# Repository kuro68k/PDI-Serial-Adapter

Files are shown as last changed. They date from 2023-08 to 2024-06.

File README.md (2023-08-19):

# PDI Serial Adapter
 Add logic level RS232 to the PDI/UPDI header, with an FTDI breakout

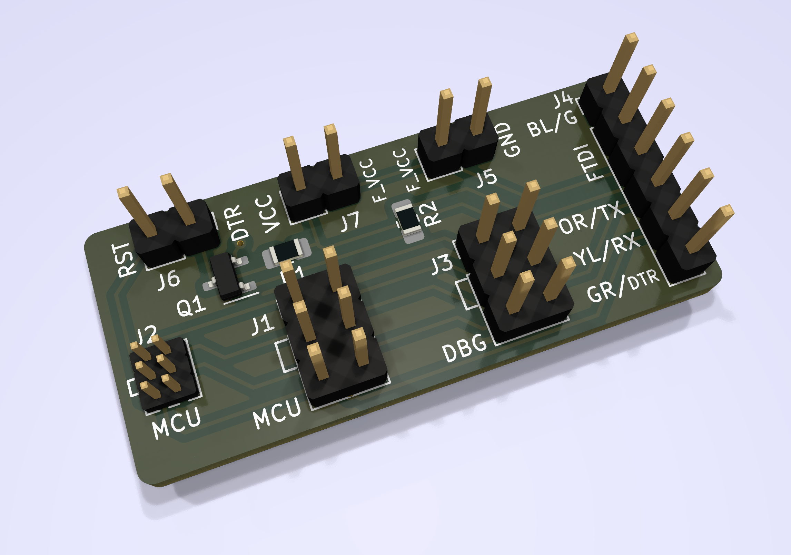
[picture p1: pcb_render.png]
raytraced PCB render


A simple 2 layer board with 3x (U)PDI headers, and an FTDI cable header. A debug serial port is really handy, and STM debuggers have one built in.

J1 (U)PDI cable to target MCU, 2.54mm pitch<br>
J2 (U)PDI cable to target MCU, 1.27mm pitch<br>
J3 (U)PDI header for debugger/programmer
J4 FTDI cable header for TTL level RS232 and USB power
J5 Easy access to FTDI_VCC (5V or 3.3V depending on the cable)
J6 Connects FTDI_DTR to MCU's reset line via open drain

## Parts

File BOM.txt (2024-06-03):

Qty	Ref	Value		Footprint
1	J1	2.54		Connector_PinHeader_2.54mm:PinHeader_2x03_P2.54mm_Vertical
1	J2	1.27		Connector_PinHeader_1.27mm:PinHeader_2x03_P1.27mm_Vertical
1	J3	PROG		Connector_PinHeader_2.54mm:PinHeader_2x03_P2.54mm_Vertical
1	J4	FTDI		Connector_PinHeader_2.54mm:PinHeader_1x06_P2.54mm_Vertical
1	J5	FTDI_VCC	Connector_PinHeader_2.54mm:PinHeader_1x02_P2.54mm_Vertical
1	J6	DTR_RST		Connector_PinHeader_2.54mm:PinHeader_1x02_P2.54mm_Vertical
1	J7	TARGET_PWR	Connector_PinHeader_2.54mm:PinHeader_1x02_P2.54mm_Vertical
1	Q1	BSS138		Package_TO_SOT_SMD:SOT-23
1	R1	100k		Resistor_SMD:R_0805_2012Metric_Pad1.20x1.40mm_HandSolder
1	R2	1k			Resistor_SMD:R_0805_2012Metric_Pad1.20x1.40mm_HandSolder

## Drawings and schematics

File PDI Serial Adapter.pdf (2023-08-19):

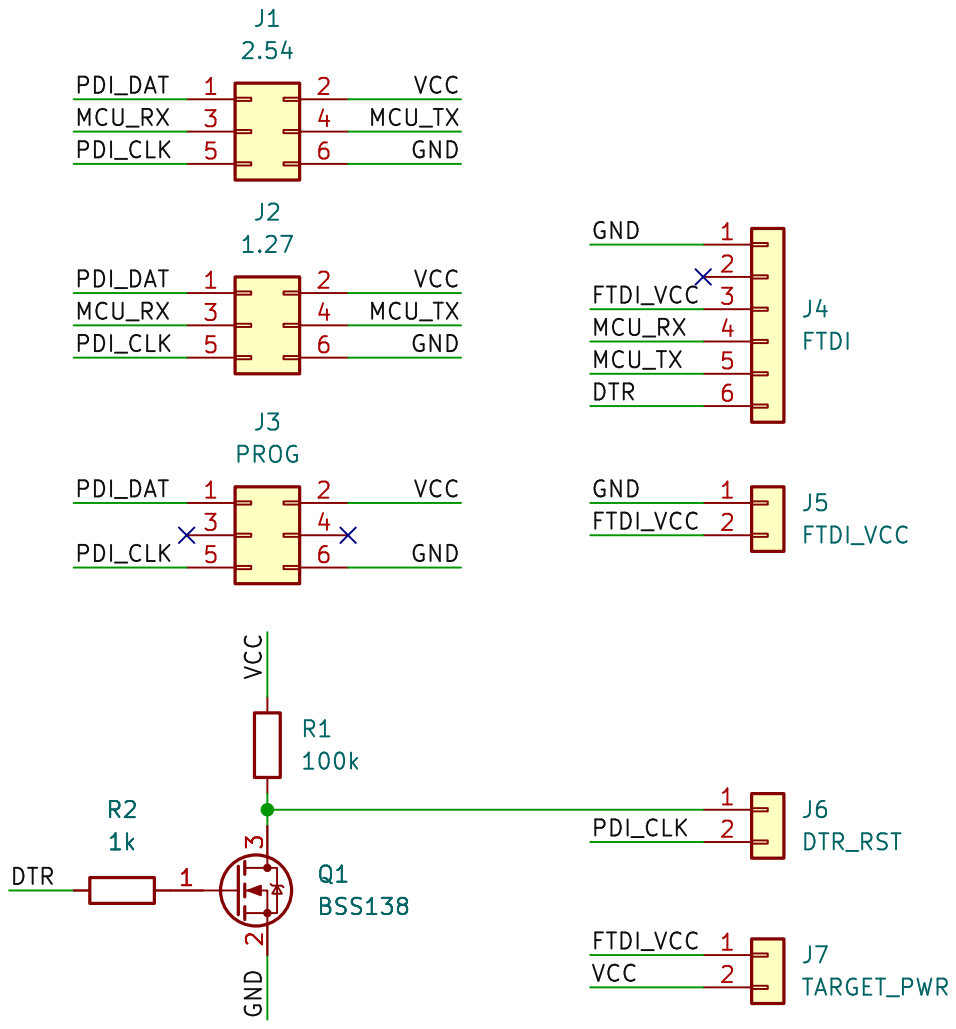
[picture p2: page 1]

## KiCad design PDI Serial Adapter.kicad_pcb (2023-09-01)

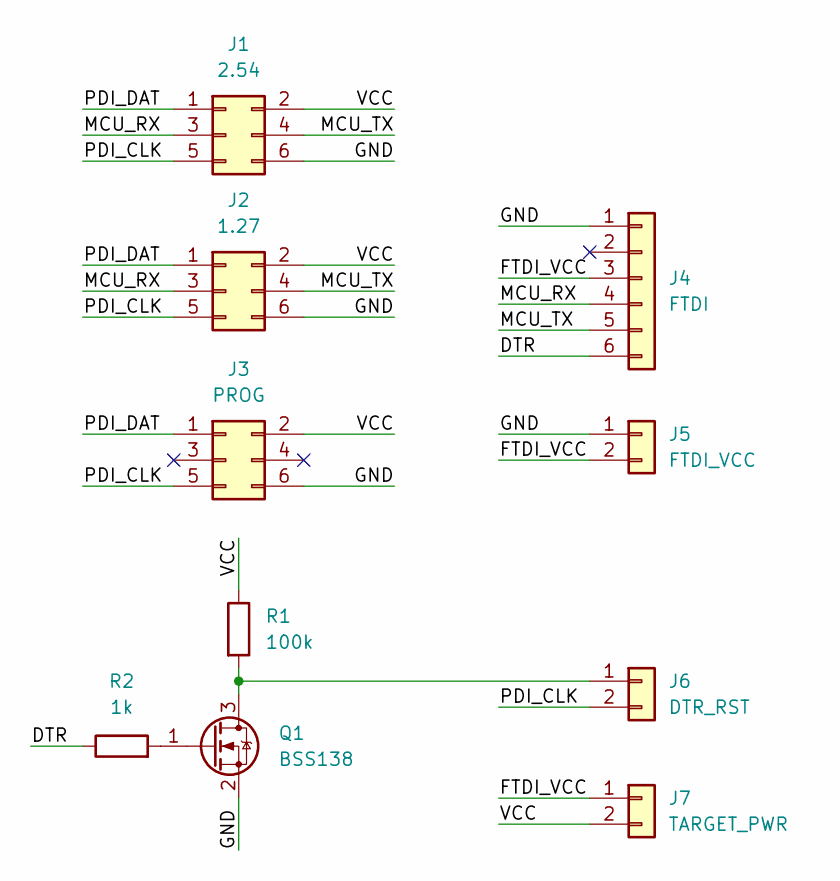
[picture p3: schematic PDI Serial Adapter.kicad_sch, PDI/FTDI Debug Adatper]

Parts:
J1: 2.54; PinHeader_2x03_P2.54mm_Vertical
J2: 1.27; PinHeader_2x03_P1.27mm_Vertical
J3: PROG; PinHeader_2x03_P2.54mm_Vertical
J4: FTDI; PinHeader_1x06_P2.54mm_Vertical
J5: FTDI_VCC; PinHeader_1x02_P2.54mm_Vertical
J6: DTR_RST; PinHeader_1x02_P2.54mm_Vertical
J7: TARGET_PWR; PinHeader_1x02_P2.54mm_Vertical
Q1: BSS138; SOT-23
R1: 100k; R_0805_2012Metric_Pad1.20x1.40mm_HandSolder
R2: 1k; R_0805_2012Metric_Pad1.20x1.40mm_HandSolder

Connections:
/DTR: J4.6, R2.1
/FTDI_VCC: J4.3, J5.2, J7.1
/GND: J1.6, J2.6, J3.6, J4.1, J5.1, Q1.2 (S)
/MCU_RX: J1.3, J2.3, J4.4
/MCU_TX: J1.4, J2.4, J4.5
/PDI_CLK: J1.5, J2.5, J3.5, J6.2
/PDI_DAT: J1.1, J2.1, J3.1
/VCC: J1.2, J2.2, J3.2, J7.2, R1.1
unnamed: J6.1, Q1.3 (D), R1.2
unnamed: Q1.1 (G), R2.2

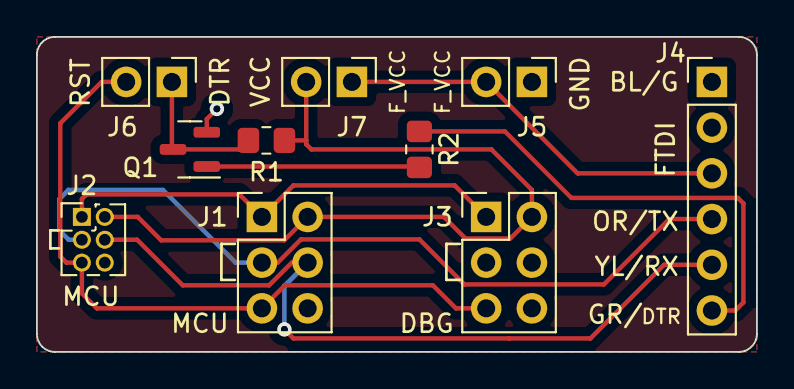
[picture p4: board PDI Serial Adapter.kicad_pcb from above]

Board: 2 copper layers, 40.0 x 17.5 mm, 10 parts (0 on the bottom side), 10 nets.

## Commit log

2023-08-19 Removed RX/TX from programmer header
    [PDI Serial Adapter.kicad_pcb, PDI Serial Adapter.kicad_sch]
2023-08-19 Open drain for DTR reset
    [PDI Serial Adapter.kicad_pcb, PDI Serial Adapter.kicad_sch]
2023-08-20 Added FTDI to silkscreen
    [PDI Serial Adapter.kicad_pcb]
2023-09-01 Fabrication settings
    [PDI Serial Adapter.kicad_pcb]
2024-06-03 Added BOM
    [PDI Serial Adapter.kicad_sch]

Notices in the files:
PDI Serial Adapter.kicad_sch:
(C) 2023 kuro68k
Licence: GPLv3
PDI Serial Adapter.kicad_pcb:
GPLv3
